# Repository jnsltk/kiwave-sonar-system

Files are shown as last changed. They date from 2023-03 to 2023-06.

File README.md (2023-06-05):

# KiWave Sonar System

```
NOTE: This repository has been imported from the private GitLab repo used throughout the development
process. As such, some of the parts that were crucial to the development are missing (for example
issues, pull requests, milestones, etc.) and some parts don't work as expected, such as the GitLab
pipelines. My personal contributions are under the users 'janos' and 'jnsltk'.
```



# Information

### Team Kiwi(Group 13) 
- Kaisa Arumeel
- Alexander Säfström
- Omid Khodaparast
- Amirpooya Asadollahnejad
- Milad Tamaddondar
- János Litkei
 
[Introductory video](https://www.youtube.com/watch?v=9HAqAKBQyas) for the project

[Final presentation video](https://www.youtube.com/watch?v=Eti_41lDb20) for the project

# Project Background/ Problem Description

The need for efficient, cost-effective, and non-invasive monitoring solutions has become increasingly important in various industries. The monitoring sonar system offers a reliable and accessible solution to security and environmental concerns. This system can be used in home security, industrial safety, parking assistance, environmental monitoring, retail analytics, and traffic management. This project builds on existing technologies and offers a customizable and expandable monitoring solution for different applications.

# Utilization

Despite the fact that the system is mainly designed for "Home Security", it has multiple other potential applications:
- Industrial safety: The system can detect objects in areas with heavy machinery and prevent accidents.
- Parking assistance: The system can detect the presence of vehicles and assist drivers in parking.
- Environmental monitoring: The system can detect changes in the environment and provide valuable insights.
- Retail analytics: The system can track the movement of customers and provide valuable data for businesses
- Traffic management: The system can detect and monitor traffic flow and help manage congestion.

# Project Description

This project aims to implement a monitoring system for a designated area or sector. The system employs two kinds of sensors: two ultrasonic sensors, a temperature sensor, and an actuator in the form of a servo motor, all of which are connected to a Wio Seeed Terminal, a microcontroller.

The core concept of the system involves mounting two ultrasonic sensors on top of a servo motor, which rotates the sensors to scan the designated area. These sensors transmit high-frequency sound waves and receive the corresponding echoes, thus detecting objects that are located in the vicinity of the ultrsonic sensors. The temperature sensor comes into play by measuring the temperature, which helps in calculation of the speed of sound in air.

The servo motor is responsible for continuously monitoring its position in degrees, while the ultrasonic sensors passe the distance data they has recieved (as a result of ultrasoic wave transmission and reception) to the microcontroller, the Wio Seeed Terminal, which then publishes this information over WiFi to the topic `KiwiSonarData`.

To provide a user-friendly interface, the front-end utilizes SvelteJS front-end framework and other JavaScript libraries to subscribe to the topic `KiwiSonarData`. Upon receiving new information, the front-end parses and displays it in the form of a radar image that showcases the range and degree of any detected object relative to the sensors.



# Used Technologies

- C++
- JAVA SCRIPT
- FIGMA
- WIO SEEED TERMINAL 
- SERVO MOTOR
- ULTRASONIC SENSOR
- TEMPERATURE SENSOR

# Documentation 

[Documents](https://github.com/jnsltk/kiwave-sonar-system/wiki)

[User Manual](https://github.com/jnsltk/kiwave-sonar-system/blob/a921cff26a3625b1a8911e5ecf0ce3f2966f95dc/Resources/User%20Manual/User_Manual_-_KiWaveSonar.pdf)

# Installation and "Get Started"

## Introduction

This projetct builds a sonar using one Wio Seed Terminal (which is Arduino compatibale), two ultrasonic sensors, one temperature sensor, and one servo motor. These parts make up the hardware required to build the sonar. The hardware parts are controlled using a GUI made using SvelteJs front-end framework. The project uses the MQTT protocol (which belongs to the Publish-Subscribe architecture style ) to connect the GUI to the Wio Seeed Terminal.

## Working with Wio Terminal and the sensors

The Wio Seeed Terminal is an Arduino compatibale microcontroller. This means that its manipulation is done using C++ (or C) programming language. To easily upload code on the Wio Seeed Terminal, you can use the [Arduino IDE](https://www.arduino.cc/en/software). There are libraries implemented for different sensors and also for the MQTT protocol in the SonarController directory:

- `KiwiServo` contains methods that are used to rotate the servo motor.
- `KiwiSonic` contains methods that are used to manipulate the ultrasonic sensors
- `KiwiTemp` contains methods that are used to manipulate the temperature sensor.
- `KiwiMQTT` contains methods that are used to manipulate the Wio Seeed Terminal to send information over the MQTT protocol.
- Note that the `SonarController.ino` is the file containing the main code which is uploaded on the Wio Seeed Terminal. It contains the `void setup()` and the `void loop()` methods that are needed for the Wio to run.

There is a file named `KiwiSecrets_template.h`. This file is meant to keep the WiFi name and and password. When you write your WiFi name (in the `ssid` attribute) and password (in the `secret` attribute), you should change the name of the file from `KiwiSecrets_template.h` to `KiwiSecrets.h`. Note that the file `KiwiSecrets.h` is put in the `.gitignore` file so that the WiFi name and password are not sent to the remote repository.

You also need to download the following libraires. You can download these by clicking on the library icon in the arduino library and search the names that are mentioned below:

- `rpcwifi.h` is needed to connect to the WiFi. You can download it by searching for `rpcwifi`.
- `PubSubClient.h` is needed for publishing data and subscribing for data to the broker using the MQTT protocol. You can download it by searching for `PubSubClient`.

The following lines will explain the pin-out instructions. Use these instructions to connect the sensors to the Wio Seeed Terminal. you can use the following images for referrence to know which pin is which.




Servo motor pinout structure:

- VCC connected to 4 (which is 5V) on the Wio
- GND connected to 6 (which is GND) on the Wio
- SIG connected to 16 (which is D2) on the Wio

First ultrasonic sensor pinout structure:

- GND connected to 30 (which is GND) on the Wio
- VCC connected to 1 (which is 3V3 (3.3 V)) on the Wio
- SIG connected to 36 (which is D7)non the Wio

Second ultrasoic sensor pinout structure:

- GND connected to 34 (which is GND) on the Wio
- VCC connected to 2 (which is 3v3 (3.3 v)) on the Wio
- SIG connected to 37 (which is D8) on the Wio

Temperature sensor pinout structure.
- Use the Multifunctional pinout under the joystick



## Working with the GUI

SvelteJS was used to make the GUI for this project. In order to use SvelteJS you need to have [Node.js](https://nodejs.org/en/download) downloaded.

The GUi initial setup was done by running the command `npm create vite@latest SonarVisualizer` in the `SonarVisualizer` as the directory name. However, if you use our project, you do not need to run the aforementioned command, but rather the commands mentioned next.

If you fork this project and and then pull from the remote repository, before using npm commands to upload the web page, you need to open a terminal in the `SonarVisualizer` directory and run the command `npm install` or `npm i`. This command downloads the dependicies and packages that are used in the project.

The GUI can be run locally for testing or development purposes. This can be done by running `npm run dev` in the terminal while in the `SonarVisualizer` directory. After running the command, the application will be accessible at http://localhost:5173. To test the application on mobile, or other devices, it can be exposed on the local network by running `npm run dev -- --host`. Following this command the application can be accessed on the local network at the local IP address of the machine it’s running on, namely at port 5173. The exact address will also be displayed in the terminal.

After installing all the required dependencies, the application can be built from source by following these steps: 

1. Using the terminal, navigate to the source directory of `SonarVisualizer`.
2. Run `npm run build` to compile the Svelte files and build the project.
3. The final result can be found in the `dist` subdirectory in the `SonarVisualizer` directory. This command is mostly used in case you want to see if all the packages, especially the extra packages you have added to the project, can be run on the browser. Moreover, it is also used if you are planning to deploy your project on a server.

If you navigate to the `src` subdirectory, you can find the different components under the `components` subdirectory. There is also a subdirectory called `data`. This directory contains the `stores.js` file which holds the information that is sent by the Wio Seeed Terminal over MQTT, and commands to be sent to the Wio Seeed Terminal by the GUI. The `App.svelte` component is the root component which contains the other components that are made under the `components` subdirectory.

Under `components` subdirectory, there is another directory called `mqtt` which conatins the `MQTTHandler.svelte` component. This component contains the publish and subscribe methods needed for the MQTT to work on the GUI.

## System Architecture

Our system, as mentioned before, made use of the MQTT protocol to create the connection between the web application and the Wio Seeed Terminal. 

What is MQTT?

MQTT is a protocol that belongs to the Publish-Subscribe architecture style. The Publish-Subscribe architecture style works in the way that different components, publish the information needed by other components to a message bus (usually called the broker) under specific topics that are defined by the developers in the code. The components that need that data need to subscribe to the broker under the same topic that was used by the component(s) that published the information. The benefits of using the publish-subscribe architecture style is that there is little coupling between the componenets. Moreover, the components can work asynchronously as they can subcribe to the broker whenever they need, hence less coupling.

Now that the base of our system's architecture is explained, you can dig deeper into our project and see how our team made use of open source Publish-Subscribe libraries. Here is a component diagram that depicts the architecture of our system. Note that the broker is shown as a component, eventhough it plays the role of a connector:

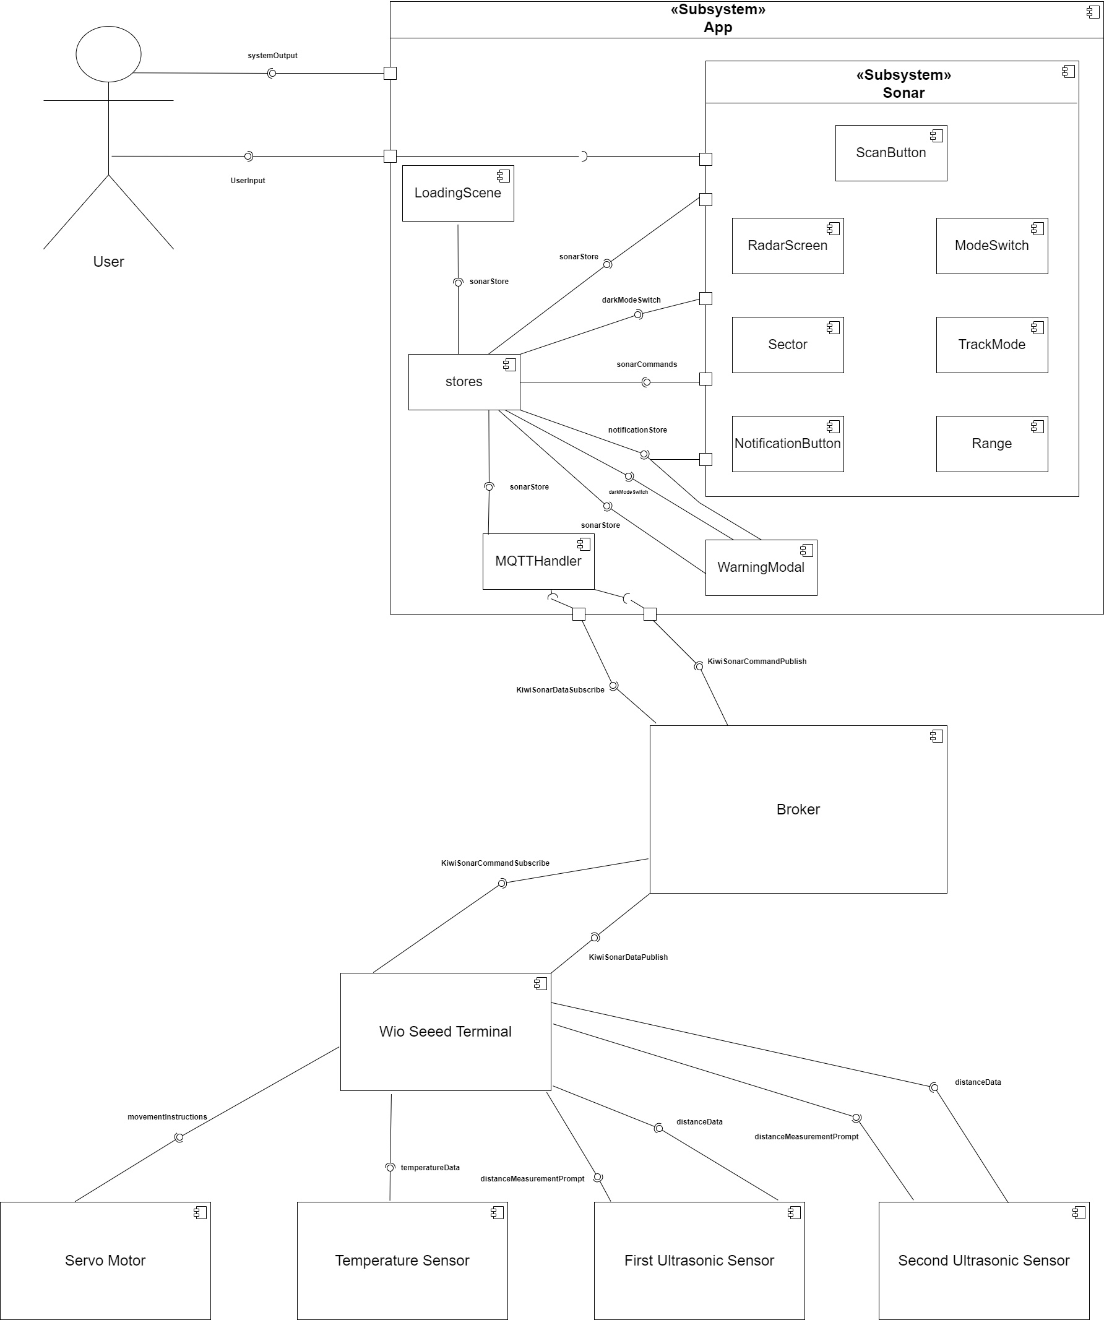
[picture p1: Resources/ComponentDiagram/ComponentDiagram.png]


As you can see in the diagram, We have two main components that communicate to each other via the broker. The App component (which is a subsystem itself), subscribes to the topic "KiwiSonarData" to receive the data that the Wio Seeed Terminal has published to the mentioned topic. The App component also publishes user's input to the KiwiSonarCommand topic. Then, the Wio Seeed Terminal subscribes to this topic and manipulates the way the sensors should work according to the user's input.

# Testing

Unit tests were made for the GUI in this project. The Jest testing framework was used to make unit tests that checked the correctness of the commands sent by the GUI and the way componenets were rendered. This section contains information regarding configuring Jest on a svelte project and the commands used to run the tests. Note that when you use `npm i` after forking our project and pulling from the remote repository, you can already use the testing commands on our project as Jest is already configured on it. The Jest configuration part is useful for those who want to configure Jest on their own projects.

## Jest configuration

Needed libraries:

1. `@babel/core`, `babel-jest` and `@babel/preset-env`are some libraires that we used. These are needed for the transpilation that is required by Jest.
2. `svelte-jester` and `jest-transform-stub`. Jest does not understand how to parse non-JavaScript files. We need to use `svelte-jester` to transform Svelte files, and `jest-transform-stub` for importing non-JavaScript assets (images, CSS, etc).
3. `@testing-library/svelte` (known as Svelte Testing Library) provides DOM query functions on top of Svelte in a way that encourages better testing practices. Some of the most commonly used functions are `render`, `getByText`, `getByLabelText`, and `getByRole`.
4. `@testing-library/user-event` is a companion library to Svelte Testing Library that provides more advanced simulation of browser interactions than the built-in fireEvent function. An example of this is if you need to trigger an event for a mouse click while the Ctrl key is being pressed.
5. If you use global environment variables or a `.env` file in your code, you need to install `babel-plugin-transform-vite-meta-env` to transform these variables for the commonJS module.
6. `@testing-library/jest-dom` provides a set of custom jest matchers that you can use to extend Jest. These can be used to make your tests more declarative. It has functions such as `toBeDisabled()`, `toBeInTheDocument()`, and `toBeVisible()`.

You can install the aforementioned libraires using npm:

```
npm install -D jest babel-jest @babel/preset-env svelte-jester jest-transform-stub @testing-library/svelte @testing-library/user-event babel-plugin-transform-vite-meta-env @testing-library/jest-dom
```

We need to configure Jest to transform our files. We must explicitly set our test environment to `jsdom`, which we are using through Jest. Since v27 Jest’s default test environment is node, we put the configuration in a specific Jest configuration file called `jest.config.json` in the project root folder (in our case in `SonarVisualizer`):

```
{
  "transform": {
    "^.+\\.js$": "babel-jest",
    "^.+\\.svelte$": "svelte-jester",
    ".+\\.(css|styl|less|sass|scss|png|jpg|ttf|woff|woff2)$": "jest-transform-stub"
  },
  "moduleFileExtensions": ["svelte", "js"],
  "testEnvironment": "jsdom",
  "setupFilesAfterEnv": ["@testing-library/jest-dom/extend-expect"]
}
```

We configure Babel to use the current version of node. Include the `babel-plugin-transform-vite-meta-env` plugin if you are using environment variables. We put the configuration in a `.babelrc` file in the project root folder (in our case in `SonarVisualizer`). Babel is a free and open-source JavaScript transcompiler that is mainly used to convert ECMAScript 2015+ code into backwards-compatible JavaScript code that can be run by older JavaScript engines. It allows web developers to take advantage of the newest features of the language.

```
{
  "presets": [["@babel/preset-env", { "targets": { "node": "current" } }]],
  "plugins": ["babel-plugin-transform-vite-meta-env"]
}
```

Add the scripts to run the tests in your `package.json`. Note that you should add them under the `scripts` object.

```
"test": "npx jest src",
"test:watch": "npm run test -- --watch"
```
sources: https://www.roboleary.net/2021/11/18/svelte-app-testing-jest.html

After following the instructions (in case you are configuring Jest on your own project), you should be able to use the command `npm run test` to run the tests that you have written for your project. Note that a test file should be named after the component that your are testing. For example, if you have a component called `Button.svelte` then the test file should be called `Button.spec.js` or `Button.test.js`. As you can see, the test file has `.spec.js` or `.test.js`. This is needed for Jest to be able to find the test files which are written in JavaScript.

</details>

</details>

# CI/CD

CI/CD stands for "continuous intergration" and "continuous development". We use the GitLab piplelines to continuously test code that is committed and and then deploy the code, if it passes the tests. The pipeline is written in `.gitlab-ci.yml` file which is usually uploaded on the root of the project (good practice to put it there). As you have noticed by now, this is a YAML file which contains commands that are executed by the GitLab runner(s). GitLab runners are computers that have Linux as their Operating System. These runners pull your project and look for the CI file and run the commands that you have given there. To install packages and programs on the runner to run your commands, most projects (our project too) use docker images. You can find docker images for the applications (programs) that you need in order to test and/or deploy your project from [docker hub](https://hub.docker.com/). Each block of commands that is executed by the GitLab runner is called a job. Note that you need to use a runner that can handle docker images. You can see the available runners under CI/CD in settings. You can see the result of your pipline under the CI/CD Pipelines section.

You can customize your `.gitlab-ci.yml` file in many ways:

- You can add stages, so that if one stage fails the rest do not run (useful in case of deployment). For example, if your test job fails, you do not want to deploy your project.
- You can customize your jobs by using the `rules` flag, so that your job runs only on specific branches or occations (in case of deployment, in the `main` branch only). 
- You can add the `before-script` to download dependencies needed by the commands that run in the `script` flag.
- You can specify the runner on which each job needs to run on using the `tags` flag.
- Note that the jobs need to have the `script` flag. A job without the `script` flag does not do anything, so it will always pass.

This is just a glimpse into what you can do using CI/CD in GitLab. Our project uses CI/CD for automated testing and deployment. It is a simple pipeline. You can use this as a starting point. You can read and learn more about the sophisticated and advanced features of GitLab CI/CD [here](https://docs.gitlab.com/ee/ci/).

# Team Members' Main Contributions

Kaisa Arumeel:

- Organised our GitLab repository by making milestones, labels and issues. Continuously updated our repository and kept track of the issues.
- Created the front-end design prototype, project name, and logo.
- Implemented the range slider and the sector specification slider features.
- Designed and implemented the loading scene.
- Implemented dark mode (including the dark mode switch and the colour scheme for the theme).
- Resposible for putting the whole front-end layout together and making it responsive.
- Edited the wiki pages and user manual.

Alexander Säfström:

- Implemented MQTT library to Wio Terminal
- Added MQTT library to front-end.
- Ported `u8-mqtt.js` to vite.
- Created `TrackMode.svelte`.
- Helped solving bugs.
- Developed algorithm for tracking objects in Wio Terminal.
- Created `MqttHandler.svelte`.
- Created main logic for periodically updating `stores.js`.

Omid Khodaparast:

- Implemented the initial KiwiServo library which is used to rotate the servo motor and tell it when to stop. This library, later in the project, went under some changes as Alexander Säfström started working on implementing the KiwiMQTT library.
- Implemented the KiwiTemp library which contains functionality used to receive the temperature data measured by the temperature sensor and calculate the temperature in degrees Celsius.
- Implemented the loading scen for the `ScanButton.svelte`component which showcases to the end user when the start and stop commands have been received by the sonar (the Wio Seed Terminal).
- Configured Jest (used to make unit tests) in the `SonarVisualizer` directory, which contains the main application used by the end users to manipulate the sonar. 
- Configured the CI/CD part of the project by creating the `.gitlab-ci.yml` and editing it by giving it different stages and different jobs to complete the automated testing and continous deployment of the project.
- Edtited and gave structure to the `README.md` file.

Amirpooya Asadollahnejad:

- Created the `ScanButton.svelte`.
- Wrote the tests for `Range.svelte` and `ScanButton.svelte` component.
- Fixed the problem with invalid inputs for `Sector.svelte`.
- Helped with the notification button styling.
- Helped in creating the initial sequence diagram.
- Polished and made different sections for wiki page and linked issues in it.
- Helped with creating the console (which the team discarded later on in the project).

Milad Tamaddondar:

- Created the Console component and made it responsive (which the team discarded later on in the project).
- Created the `WarningModal.svelte` component for the alarm and notification.
- Created `NotificatonButton.svelte`component for disabling and enabling the notification and alarm feature.
- Designed the sequence diagram and modified it.
- Edited the wikipage and wrote in the `README.md` file.
- Wrote in the user manual.
- Removed Unnecessary files form the repository.
- Implemented the library which is used to measure distance from ultrasonic sensors.
- Tested the ultrasonic sensors to work accurately in environments with different temperatures.
- Tested the temperature sensor to work accurately. 

János Litkei:

- Created the 3D model for the 3D printed mount to fix the ultrasonic sensors on the servo. In the final product we ended up not using it.
- Implemented the RadarScreen component of the front-end, which interprets and visualises the data received from the sensors.
    - Created the methods for processing the data received from the sensors.
    - Implemented the visualisation of the data.
    - Made the RadarScreen component responsive.
    - Implemented tooltips showing object-meausrement data on the RadarScreen component.
- Set up private MQTT broker for better reliability.
- Worked on the deployment of the frontend on a VPS, as part of the CI/CD pipelines.
- Edited the user manual.

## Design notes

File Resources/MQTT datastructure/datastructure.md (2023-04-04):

# MQTT Data structure

This file describes the string representation of the data structure that is used to send data from the Wio Terminal to the SonarVisualizer app using the MQTT protocol. 

The Wio terminal sends a number representing the degree that it's currently looking at and measuring, and the corresponding distance value. This data is represented in a json object.

Here's an example of the data format:

```json
{
    "deg": "125",
    "dist": "24.56"
}
```

The data is sent as a string on the MQTT protocol, which then can be parsed into a JavaScript object by the SonarVisualizer.

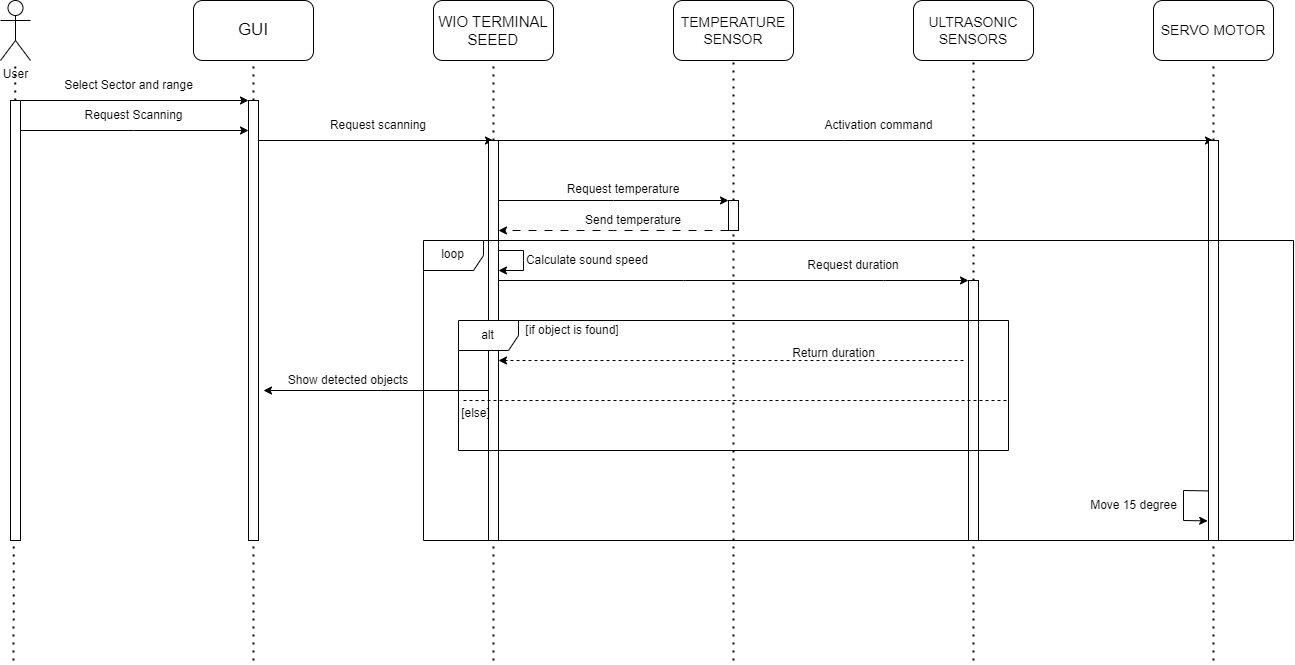
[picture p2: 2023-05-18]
Resources/Sequence diagram/UpdatedSequenceDiagram.png

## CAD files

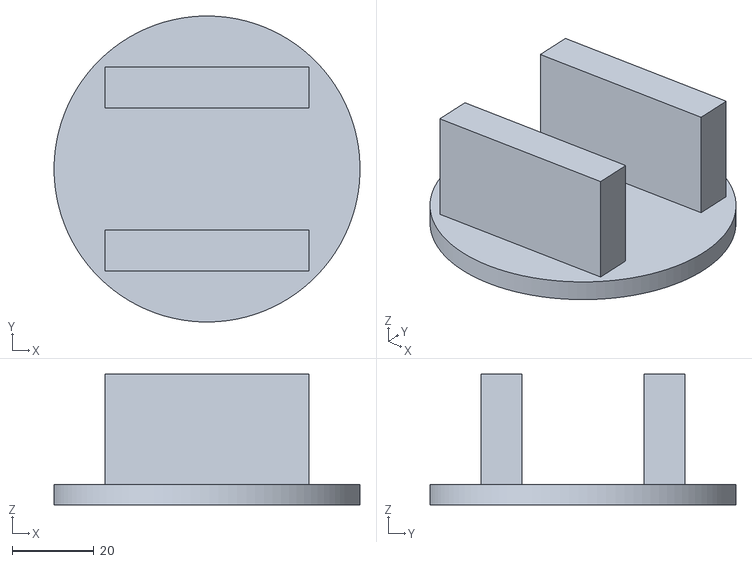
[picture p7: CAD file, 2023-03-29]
Resources/3D-model/v2.stl
75.0 x 75.0 x 32.0

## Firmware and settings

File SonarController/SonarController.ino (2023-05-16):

#include "Arduino.h"
#include "KiwiMQTT.h"
#include "KiwiSecrets.h"
#include "KiwiSonic.h"
#include "KiwiTemp.h"
#include "KiwiServo.h"
#include "math.h"


KiwiSonic ultrasonicSensor1(D7,350);
KiwiSonic ultrasonicSensor2(D8,350);
KiwiTemp tempSensor(A0);
KiwiServo servo(D2);
KiwiMQTT wireless(ssid,secret);

const int STANDARD_DELAY=100; //Used to delay certain operations for readability or stability.
const int SOUNDWAVE_DISSIPATION_DELAY=250; //Used to prevent accumulation of sound waves when used in smaller rooms.
const long UPDATE_INTERVAL=5000; //How often are we going to fetch new messages from MQTT.
const int MAX_MEASUREMENTS=5; //Maximum measurements

bool servoRun=false;
bool track=false;
bool result=false;
float temperature=0;
int maxRange1=999;
int maxRange2=999;
long lastUpdateTime=0;
int from=0;
int to=180;
void safeDelay(int ms){
  long timeRunning=millis();
   while((millis()-timeRunning)<ms){
    //Perform non-blocking delay.
   }
}

uint8_t STP[3]={83,84,80}; //Stop
uint8_t STR[3]={83,84,82}; //Start
uint8_t SSR[3]={83,83,82}; //Set sector
uint8_t SRR[3]={83,82,82}; //Set range
uint8_t TRK[3]={84,82,75}; //Track
uint8_t SRK[3]={83,82,75}; //Stop Track
int sonar1Measurement[5]={-1,-1,-1,-1,-1};
int sonar2Measurement[5]={-1,-1,-1,-1,-1};
int degrees[5]={-1,-1,-1,-1,-1};
int measurementsMade=0;

void callback(char* topic, uint8_t* data, unsigned int msglen){
  //We know that the msg header is the first three bytes.
  //We loop through the first three bytes of the message and copy it to the messageHeader holder variable.
    uint8_t msgHeader[3]; //Message header has length 3.
    for(int i=0;i<3;i++){
      msgHeader[i]=(uint8_t) data[i]; //Retrieving the message header of the command.
    }
     /*
     * We use the method call: memcmp() to compare if the receive message header
     * matches any of the defined commands.
     **/
  if (memcmp(msgHeader,STP,sizeof(msgHeader))==0){
        Serial.println("RCV: Stop Sonar");        
        servoRun=false;
        wireless.publish("RCVD");

        Serial.println("Stopping sonar");
    } else if(memcmp(msgHeader,STR,sizeof(msgHeader))==0){
        Serial.println("RCV: Start Sonar");        
        servoRun=true;
        wireless.publish("RCVD");

        Serial.println("Starting sonar");
    } else if(memcmp(msgHeader,TRK,sizeof(msgHeader))==0){
        Serial.println("RCV: Tracking mode");        
        track=true;
        wireless.publish("RCVD");

        Serial.println("Starting sonar");
    }else if(memcmp(msgHeader,SRK,sizeof(msgHeader))==0){
        Serial.println("RCV: Stop Tracking mode");        
        track=false;
        wireless.publish("RCVD");

        Serial.println("Starting sonar");
    } else if(memcmp(msgHeader,SSR,sizeof(msgHeader))==0){
        Serial.println("RCV: Go To Sector"); 
        char charFrom[3];
        char charTo[3]; 

        int c=0;
        for(int i=3;i<6;i++){
          Serial.println((char) data[i]);

          charFrom[c]=(char) (data[i]);
          c++;
        }
        c=0;
        for(int i=6;i<9;i++){
          charTo[c]=(char) (data[i]);
          c++;
        }
        Serial.println("Sector Set");
        String strFrom=String(charFrom);
        String strTo=String(charTo);
        from= (strFrom).toInt();
        to=(strTo).toInt();
        Serial.println(from);
        Serial.println(to);
        wireless.publish("RCVD");

    }else if(memcmp(msgHeader,SRR,sizeof(msgHeader))==0){
        Serial.println("RCV: Set Range"); 
        char charMaxRange1[3];
        char charMaxRange2[3]; 

        int c=0;
        for(int i=3;i<6;i++){
          charMaxRange1[c]=(char) (data[i]);
          c++;
        }
        c=0;
        for(int i=6;i<9;i++){

          charMaxRange2[c]=(char) (data[i]);
          c++;
        }
        Serial.println("Range Set");

        String strMaxRange1=String(charMaxRange1);
        String strMaxRange2=String(charMaxRange2);
        maxRange1= (strMaxRange1).toInt();
        maxRange2=(strMaxRange2).toInt();
        Serial.println(strMaxRange1);
        Serial.println(strMaxRange2);        
        wireless.publish("RCVD");

    }

}

void setup(){
  //Delaying for 5 seconds so that some older systems have time to register the initial messages.
  //Connecting to WiFi
  //Awaiting a successful WiFi connection
Serial.begin(115200);
Serial.println("Measuring temperature");
temperature=tempSensor.measureTemp();

Serial.println(temperature);
  wireless.init();

while(wireless.getWiFiStatus()!=WL_CONNECTED){
  Serial.println("Initial connect failed... Attempting reconnect.");
  wireless.init();
  safeDelay(1000);
}
Serial.println("Wifi set.");
wireless.setServer("mqtt-http.jnsl.tk", 1883);
Serial.println("Server set");
wireless.setCallback(callback);
Serial.println("Callback set");
}

void sendBundle(){
  /*
  * Format buffer segment in accordance with specified format.
  */
  String bundle=String("M");
  for(int i=0;i<MAX_MEASUREMENTS;i++){
    bundle=bundle+String("/")+sonar1Measurement[i]+String("/")+sonar2Measurement[i]+String("/")+degrees[i];
  }
  wireless.publish(bundle);
}

bool record(int degree){
  if(measurementsMade>=MAX_MEASUREMENTS){
    /*
    * We have reached the maximum number of measurements for this buffer segment, send it over MQTT.
    */
    sendBundle();
    measurementsMade=0;    
  }
  
  int measure1=ultrasonicSensor1.calculateDistance(temperature);
  safeDelay(SOUNDWAVE_DISSIPATION_DELAY);
  int measure2=ultrasonicSensor2.calculateDistance(temperature);
  int reportedMeasurement1=measure1<maxRange1?measure1:-1;
  int reportedMeasurement2=measure2<maxRange2?measure2:-1;
  sonar1Measurement[measurementsMade]=reportedMeasurement1;
  sonar2Measurement[measurementsMade]=reportedMeasurement2;
  degrees[measurementsMade]=degree;
  measurementsMade=measurementsMade+1;
  if(track && reportedMeasurement2>-1){
    return true;
  } 
  return false;
}

void spin(){
  /*
  * This method is responsible for moving the ultrasonic sensor and tracking objects if tracking mode is enabled.
  */
  if(servoRun){
  for(int i=from;i<to;i+=15){
    servo.goTo(i);
    if(record(i)){
      if(track){
        /*
        * If track mode is activated we enter the track mode.
        */
        int degree=i;
        bool keepTracking=true;
        while(keepTracking){
          safeDelay(STANDARD_DELAY);
          wireless.publish("TRK");
          wireless.sweep();          
          bool res=record(degree); //Checking if anything is in our vicinity at the current degree.
          if(!res){ //If nothing is seen we need to check if there is something to the left.
            if((degree-15)>0){ //Ensure we are not going to break the servo.
              servo.goTo(degree-15);
              if(record(degree-15)){ //Record at new degree 
                  degree=degree-15; //If we found something at degree-15, let this be the new value of degree.
              } else if((degree+15)<180) { //If we are going to break the servo by going more left, we should check if we can go right.
              servo.goTo(degree+15);
                if(record(degree+15)){
                  degree=degree+15; //If we found something at degree+15, let this be the new value of degree.
                } else {
                    keepTracking=false; //If both directions were checked and nothing was found, drop the object.
                }
              }
            } else if((degree+15)<180) {
              /*
              * Same process as above but inverted.
              */
              servo.goTo(degree+15);
                if(record(degree+15)){
                  degree=degree+15;
                } else if((degree-15)>0){
              servo.goTo(degree-15);
                  if(record(degree-15)){
                    degree=degree-15;
                  } else {
                    keepTracking=false;
                  }
                }
            }
          }
        }
  

        }
   
      }
    }
    safeDelay(STANDARD_DELAY);
      for(int i=to;i>from;i-=15){
    servo.goTo(i);
    if(record(i)){
      if(track){
        /*
        * If track mode is activated we enter the track mode.
        */
        int degree=i;
        bool keepTracking=true;
        while(keepTracking){
          safeDelay(STANDARD_DELAY);
          wireless.publish("TRK");
          wireless.sweep();          
          bool res=record(degree); //Checking if anything is in our vicinity at the current degree.
          if(!res){ //If nothing is seen we need to check if there is something to the left.
            if((degree-15)>0){ //Ensure we are not going to break the servo.
              servo.goTo(degree-15);
              if(record(degree-15)){ //Record at new degree 
                  degree=degree-15; //If we found something at degree-15, let this be the new value of degree.
              } else if((degree+15)<180) { //If we are going to break the servo by going more left, we should check if we can go right.
              servo.goTo(degree+15);
                if(record(degree+15)){
                  degree=degree+15; //If we found something at degree+15, let this be the new value of degree.
                } else {
                    keepTracking=false; //If both directions were checked and nothing was found, drop the object.
                }
              }
            } else if((degree+15)<180) {
              /*
              * Same process as above but inverted.
              */
              servo.goTo(degree+15);
                if(record(degree+15)){
                  degree=degree+15;
                } else if((degree-15)>0){
              servo.goTo(degree-15);
                  if(record(degree-15)){
                    degree=degree-15;
                  } else {
                    keepTracking=false;
                  }
                }
            }
          }
        }
  

        }
   
      }
    safeDelay(STANDARD_DELAY);
    }
  }

  }



void loop(){
  if(!wireless.getBrokerStatus()){
    Serial.println("Broker disconnected");
    wireless.connect();
    Serial.println("Connected");
  } else {
    long currentTime=millis(); //Retrieving the number ms the Wio terminal has been alive.
    if((currentTime-lastUpdateTime)>=UPDATE_INTERVAL){
      /*
      * This part can get stuck, this is why have enabled logging, for debugging purposes in case
      * the sonar gets stuck. 
      **/
      Serial.println("Sweep");
      lastUpdateTime=currentTime; //Updating the variable that keeps track how often we fetch new messages.
      result=wireless.sweep(); //Fetching new messages from MQTT broker.
      wireless.publish("CNCTD");  //Short for connected. We send this to let front-end know we are connected and subcribed to topic.
      Serial.println(result);
      if(result==1){
          spin(); //Perform rotation in accorance to the specified sector.
      }
    }
  }
}

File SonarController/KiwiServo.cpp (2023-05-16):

/*
*/

#include "Arduino.h"
#include "KiwiServo.h"

KiwiServo::KiwiServo(int sigPin) {
    _sigPin = sigPin;
    pinMode(_sigPin, OUTPUT); //We need to transmit signals.
}

int KiwiServo::convertAngleToPulse(float angle) {
    float angleInSeconds=2000/180; //Scaling seconds in relation to the angle
    float minDelay=500;  //Minimum delay (corresponds to degree 0)
    float convertedAngle = angle*(150.0/180.0); //Scaling the received angle to a max value of 150
    //Returning the number of seconds to delay.
    return(((angleInSeconds)*(convertedAngle))+minDelay); 
}

void KiwiServo::goTo(float angle) {
    //Transmit voltage to servo
        digitalWrite(_sigPin, HIGH);
    //Delaying by seconds required to move servo to a certain angle.
        delayMicroseconds(convertAngleToPulse(angle)); 
    //Stopping signal transmission to servo
    digitalWrite(_sigPin, LOW);
}

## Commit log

2023-03-29 This folder contains source files that will control ultrasonic sensors, servo motors and temperature sensors.
2023-03-29 #2 Finish 3D model
    [v2.stl]
2023-04-01 Ultrasonic sensor library
    I found the Grove Ultrasonic Library from the Wio Seeed website and I have added it under resourece in Arduino Library
2023-04-01 Distance Measurement Example
    this c++ file is a teset code that measures distancee from the ultrasonic sensor and prints it in mm and cm. However, when running this using the wio terminal and the ultrasonic sensor, it did not print the distance of the objects accurately and the output was zero all the time. I am commiting this so that everybody can work on this and help with the problem encountered
2023-04-01 TempMeasure method
    this peace of C++ code implements a method that measures the temperature using the temperature sensor. There are different variables in the beginning of the code and each is explanied and the source 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
2023-04-03 Task 4 - Front-end design prototype
    Created Figma prototype for the GUI.
2023-04-03 Task 4 - Front-end design prototype
    Updated figma prototype for the GUI.
2023-04-07 #10 (Servo motor), #11 (Distance from sesnors), #12 (Temperature sensor), #14 (SoundwavesWorking in different temperatures)
    Have finished commenting and making the libraries for the sensors. The code is well commented. There are different functionalities and methods for each sesnor's library. THe temperature is also taken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
2023-04-07 #16 Stop and start the sonar
    Impelements button for controlling sonar for now it just contains the gui, mqtt will be added later.
2023-04-10 #15 Add sonar range to sonarData in stores.js
2023-04-13 #31, #27, #28 - Added comments
    Improved comments and fixed typos
    [KiwiServo.cpp, KiwiSonic.cpp]
2023-04-13 #31 fixed Typos in the SonarController Directory
    The typos in the comments were fixed. Moreover, the spinmethod for the Servo library was changed.
    [KiwiServo.cpp, KiwiSonic.cpp, SonarController.ino]
2023-04-13 #28 - Got MQTT working
    Implementation of MQTT is working. Next is establishing communication to actuators and sensor.
2023-04-13 Mistake found in temperature sensor and ultrasonic sensor
    [KiwiSonic.cpp, SonarController.ino]
2023-04-13 Control servo from mqtt
2023-04-14 #28 Added Range command and tested for stability
    [KiwiSonic.cpp, SonarController.ino]
2023-04-15 #33 User Story: Responsive Start/Stop Button
    Scan button responses to different sizes
2023-04-16 #28 Added delay to minimize interference.
    [KiwiServo.cpp, KiwiSonic.cpp, SonarController.ino]
2023-04-16 #28 Fixed compilation error prior to merge
    [SonarController.ino]
2023-04-19 #38 Update sonarStore variables
2023-04-19 #16 stop/start the sonar
    some changes are made to scanbutton
2023-04-19 #16 start/stop sonar
    One unnecessary file accidentally was added in previous commit is removed
2023-04-23 Cut unnecessary space from KiWave.png
2023-04-24 #40 configuring jest on the project
    Jest is configured on the SonarVisualizer and all that needs to be done other people's side is to do npm i in the command prompt in SonarVisualizer
2023-04-24 Stye all components together
    Aligned the controllers, made the whole screen responsive for computer, tablet and phone sized screen. Also commented on range and sector and removed unnecessary button classes.
2023-04-26 Darkmode switch and first version of dark mode
2023-04-27 #25 Scan button testing
    implements base files for testing
2023-04-27 #25 Scan button testing
    implements a test for scan button which checks the respond to clicking the scan button
2023-04-28 #53 Fix RadarScreen, display currently measured sectors
2023-04-29 #45 Job creation for the test
    created a job that runs npm run test for the test made for scan button
2023-05-03 Change sarkmode radar object and stop button colours
2023-05-03 Finished track mode with GUI element
2023-05-03 Added track mode to Wio Terminal
2023-05-04 Create header div for logo and dark-mode switch
    Create header div for logo and dark-mode switch, delete unnecessary code, fix layout issues related to logo and added margin to the screen.
2023-05-04 Switch loading scene on
2023-05-06 #55 Start button Loading scene
    I used the loading scen that Kaisa had made, made some changes to the way the lastCommandReceived when the user toggels over the button. I wanted to render the loading scene on the button, but I could not find a way for that as it would cause the test to fail. This is the best I came up with
2023-05-06 #55 Start button loading scene
    I had missed setting the background clour of the loading scene for the class attribute recieved. I changed it by setting to a clour, so that no matter starting or stopping the sonar, it has the same colour, which implies to the end user that they need to wait for the sonar to recieve their last command
2023-05-07 #73 ScanButton test extension
    implements a extended test file for testing store.js data coresponding to button clicking
2023-05-07 #55 Start button loading scene
    I had changed isOnline variable to true, so that i could see the GUI, but forgot to change it upon commit last time. Therefore, i am changing it back to false, so that sonar does not run unitl wio is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
2023-05-08 #55 Start Button Loading Scene
    As the comment on the merge request mentioned a mistake that I had made in one line of the code. I did what I was recommended and it is fixed now.
2023-05-08 #68 Deployment on VPS
    Janos and I changed the YML file, so that it has stages and it will deploy the GUI on his VPS.
2023-05-08 #55 start button loading scene
    I added inline styling, so that the redundancy is removed.
2023-05-10 #49 & #50
    I changed the component based on the results from testing. Since the web page did not work. I made it in a way that there will be a pop up for 30 cm and both pop up and an alarm for 20cm and I have set a timer for it so that it will stop after 4 seconds.
2023-05-10 #68 Deployment on VPS
    Create separate build and deploy stages
2023-05-12 Added simulation of active sonar.
2023-05-13 #49 & #50
    replace the timer with a close button and added a feature so that the end user can disable to notificaton feature
2023-05-13 #50 & #49 notification and alarm
    I tested it using a stimulationmode that would generate random data, I also tested the button for disabling these feature
2023-05-14 Change button measurements
2023-05-14 Fixed problems with sector and range
    [SonarController.ino]
2023-05-17 Add notification button back to sonar.svelte
2023-05-18 #81 unused files
    I removed the unused files from the public folder from the sonar visualizer
2023-05-18 #79 sequence diagram modification
    there were two prblems with the sequence digram, one that the temperature message should be sent once and not in the loop, and that the sonar scans every 15 degree other than one degree at a time
2023-05-18 #79 sequence diagram modifications
    There were two problems with the existing sequence diagram. One was that the temperature message should be sent only once rather than being in the loop and the sonar moves 15 degree at a time rather than one
2023-05-18 #63 ReadMe polishing. This is a picture of the sonar intended to be uploaded in the ReadMe in another commit
2023-05-18 #63 ReadMe Polishing. This uploads the inner sonar structure picture. Which will be used in the ReadMe.
2023-05-18 #63 ReadMe Polishing. This commit uploads the sonar outer look which will be used in project description to give a better understanding of the project to different developers
2023-05-19 #63 ReadMe polishing. I added a directory to hold the Sonar pictures that I added under resources.
2023-05-19 #63 ReadMe polishing. I added the SonarOuterLook PNG file to be used in the README.
2023-05-19 #63 ReadMe polishing. I added the SonarInnerStrcture PNG file which is to be used in README
